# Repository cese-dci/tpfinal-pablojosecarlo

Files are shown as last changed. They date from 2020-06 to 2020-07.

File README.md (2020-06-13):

# tpfinal-pablojosecarlo

DCI CESE 10º Cohorte 2020 Pablo José Carlos Alonso Castillo

Escaner de Campos Magnéticos Superficiales (ECMag)

Descripción del dispositivo:

El objeto del scanner  es relevar los campos magnéticos a distancias de 1 a 3 mm de las superficies, correlacionando la posición de sensores magnéticos con la de un encoder absoluto y comunicar los resultados a una PC via cable USB, RS232 o por medios inalámbricos 
 
Para ese fin se implementa un circuito dividido en dos secciones con los uP ATM328 y PIC18F2550

El ATM328 se encarga de la adquisición de señales del encoder alsoluto de 12 bits, de los sensores magnéticos y de la interfaz de usuario a través de un display i2c, un buzzer y dos pulsadores.

El PIC18F2550 se encarga de las comunicaciones USB, seriales e inalámbricas y de servir de buffer de datos.

los uP cuentan con pulsadores de reseteo.

Puesto que el encoder funciona con 12V se ha dispuesto también de un convertidor DC-DC de 5V a 12V

La alimentación puede ser desde el puerto USB o con fuente externa de 5V

La salida a display i2c muestra las lecturas instantáneas de los campos magnéticos y la posición del encoder; buzzer de fuera de rango y dos pulsadores de seteo y nueva medición.

Pablo J.C. Alonso Castillo

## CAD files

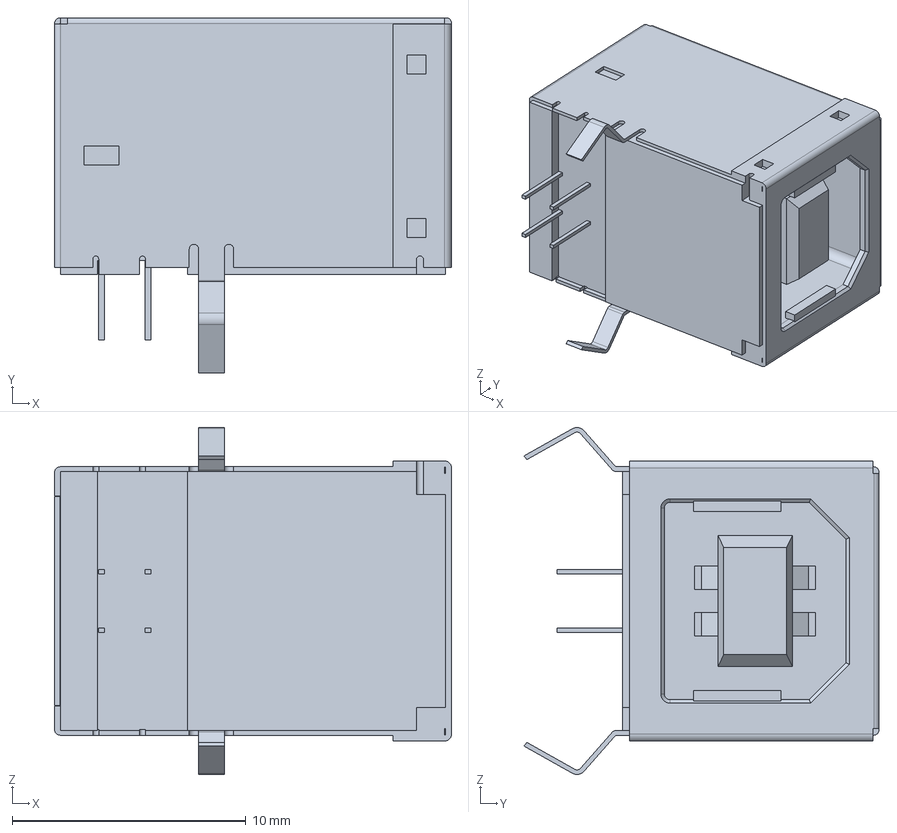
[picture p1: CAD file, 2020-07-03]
Shapes3D/USB_B_OST_USB-B1HS00_Horizontal.step
17.0 x 15.2 x 14.9 mm

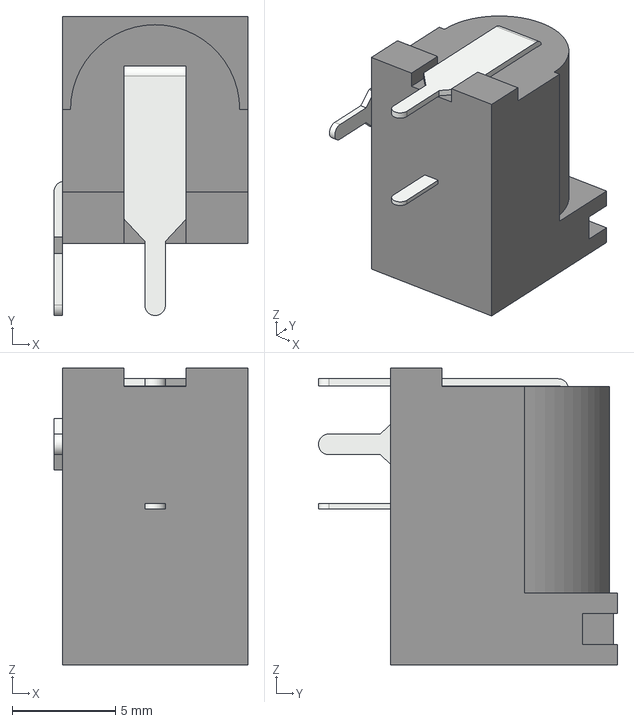
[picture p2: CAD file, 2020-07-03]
Shapes3D/CUI_PJ-102A.STEP
9.40 x 14.5 x 14.4 mm

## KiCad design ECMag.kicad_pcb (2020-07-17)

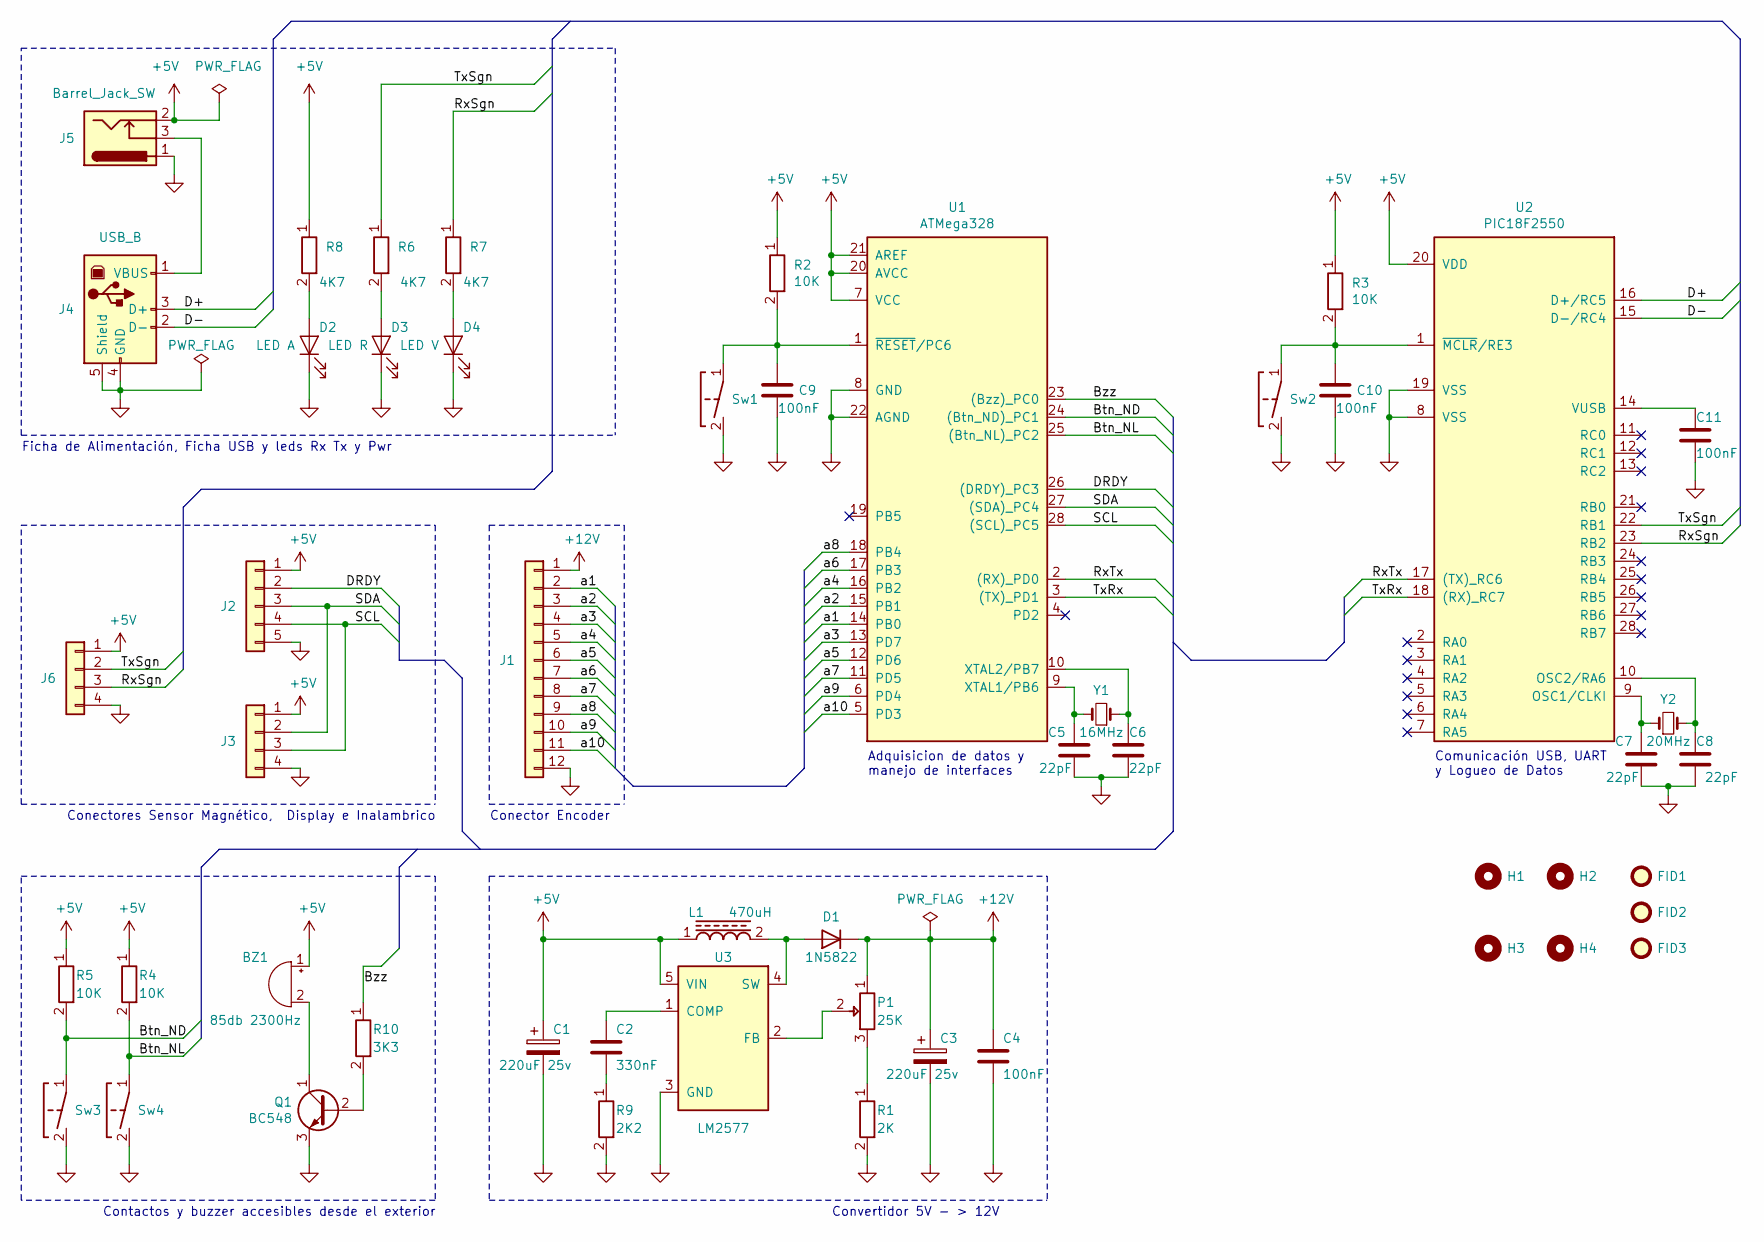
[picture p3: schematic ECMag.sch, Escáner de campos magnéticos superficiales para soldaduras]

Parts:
BZ1: 85db 2300Hz; Buzzer_12x9.5RM7.6; Digikey 102-1458-ND
C1, C3: 220uF 25v; CP_Radial_D8.0mm_P5.00mm
C2: 330nF; C_Disc_D5.1mm_W3.2mm_P5.00mm
C4, C9, C10, C11: 100nF; C_Disc_D5.1mm_W3.2mm_P5.00mm
C5, C6, C7, C8: 22pF; C_Disc_D6.0mm_W2.5mm_P5.00mm
D1: 1N5822; D_A-405_P10.16mm_Horizontal; Digikey 497-11370-1-ND
D2: LED A; LED_D3.0mm
D3: LED R; LED_D3.0mm
D4: LED V; LED_D3.0mm
FID1, FID2, FID3: Fiducial; Fiducial_1mm_Mask2mm
H1, H2, H3, H4: MountingHole; MountingHole_3.2mm_M3
J1: Conn_01x12; PinHeader_1x12_P2.54mm_Vertical; Digikey 952-3302-ND
J2: Conn_01x05; PinHeader_1x05_P2.54mm_Vertical; Digikey 952-3302-ND
J3, J6: Conn_01x04; PinHeader_1x04_P2.54mm_Vertical; Digikey 952-3302-ND
J4: USB_B; USB_B_OST_USB-B1HSxx_Horizontal; Digikey WM12785-ND
J5: Barrel_Jack_SW; BarrelJack_Wuerth_6941xx301002; Digikey CP-202A-ND
L1: 470uH; L_Radial_D7.5mm_P5.00mm_Fastron_07P; Digikey 445-174743-2-ND
P1: 25K; Potentiometer_Bourns_3266W_Vertical
Q1: BC548; TO-92_Inline; Digikey BC548-ND
R1: 2K; R_Axial_DIN0207_L6.3mm_D2.5mm_P7.62mm_Horizontal
R2, R3, R4, R5: 10K; R_Axial_DIN0207_L6.3mm_D2.5mm_P7.62mm_Horizontal
R6, R7, R8: 4K7; R_Axial_DIN0207_L6.3mm_D2.5mm_P7.62mm_Horizontal
R9: 2K2; R_Axial_DIN0207_L6.3mm_D2.5mm_P7.62mm_Horizontal
R10: 3K3; R_Axial_DIN0207_L6.3mm_D2.5mm_P7.62mm_Horizontal
Sw1, Sw2, Sw3, Sw4: Tactil Switch B3F NA; SW_PUSH_6mm_H5mm; Digikey B3F-1060
U1: ATMega328; DIP-28_W7.62mm; Digikey ATMEGA328-PU-ND
U2: PIC18F2550; DIP-28_W7.62mm; Digikey PIC18F2550-I/SP-ND
U3: LM2577; TO-220-5_P3.4x3.7mm_StaggerOdd_Lead3.8mm_Vertical; Digikey LM2577SX-ADJ/NOPBTR-ND
Y1: 16MHz; Crystal_HC49-U_Vertical; Digikey 1923-1788-ND
Y2: 20MHz; Crystal_HC49-U_Vertical; Digikey 1923-1441-ND

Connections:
+5V: BZ1.1 (-), C1.1, J2.1, J3.1, J5.2, J6.1, L1.1, R2.1, R3.1, R4.1, R5.1, R8.1, U1.7 (VCC), U1.20 (AVCC), U1.21 (AREF), U2.20 (VDD), U3.5 (VIN)
+12V: C3.1, C4.1, D1.2 (K), J1.1, P1.1
/Btn_ND: R5.2, Sw3.1, U1.24 ((Btn_ND)_PC1)
/Btn_NL: R4.2, Sw4.1, U1.25 ((Btn_NL)_PC2)
/Bzz: R10.1, U1.23 ((Bzz)_PC0)
/D+: J4.3 (D+), U2.16 (D+/RC5)
/D-: J4.2 (D-), U2.15 (D-/RC4)
/DRDY: J2.2, U1.26 ((DRDY)_PC3)
/RxSgn: J6.3, R7.1, U2.23 (RB2)
/RxTx: U1.2 ((RX)_PD0), U2.17 ((TX)_RC6)
/SCL: J2.4, J3.3, U1.28 ((SCL)_PC5)
/SDA: J2.3, J3.2, U1.27 ((SDA)_PC4)
/TxRx: U1.3 ((TX)_PD1), U2.18 ((RX)_RC7)
/TxSgn: J6.2, R6.1, U2.22 (RB1)
/a1: J1.2, U1.14 (PB0)
/a2: J1.3, U1.15 (PB1)
/a3: J1.4, U1.13 (PD7)
/a4: J1.5, U1.16 (PB2)
/a5: J1.6, U1.12 (PD6)
/a6: J1.7, U1.17 (PB3)
/a7: J1.8, U1.11 (PD5)
/a8: J1.9, U1.18 (PB4)
/a9: J1.10, U1.6 (PD4)
/a10: J1.11, U1.5 (PD3)
GND: C1.2, C3.2, C4.2, C5.2, C6.2, C7.2, C8.2, C9.2, C10.2, C11.2, D2.1 (K), D3.1 (K), D4.1 (K), J1.12, J2.5, J3.4, J4.4 (GND), J4.5 (Shield), J5.1, J6.4, Q1.3 (E), R1.2, R9.2, Sw1.2, Sw2.2, Sw3.2, Sw4.2, U1.8 (GND), U1.22 (AGND), U2.8 (VSS), U2.19 (VSS), U3.3 (GND)
unnamed: BZ1.2 (+), Q1.1 (C)
unnamed: C2.1, U3.1 (COMP)
unnamed: C2.2, R9.1
unnamed: C5.1, U1.9 (XTAL1/PB6), Y1.2
unnamed: C6.1, U1.10 (XTAL2/PB7), Y1.1
unnamed: C7.1, U2.9 (OSC1/CLKI), Y2.1
unnamed: C8.1, U2.10 (OSC2/RA6), Y2.2
unnamed: C9.1, R2.2, Sw1.1, U1.1 (~RESET~/PC6)
unnamed: C10.1, R3.2, Sw2.1, U2.1 (~MCLR~/RE3)
unnamed: C11.1, U2.14 (VUSB)
unnamed: D1.1 (A), L1.2, U3.4 (SW)
unnamed: D2.2 (A), R8.2
unnamed: D3.2 (A), R6.2
unnamed: D4.2 (A), R7.2
unnamed: J4.1 (VBUS), J5.3
unnamed: P1.2, U3.2 (FB)
unnamed: P1.3, R1.1
unnamed: Q1.2 (B), R10.2

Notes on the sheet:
Convertidor 5V - > 12V
Conector Encoder
Contactos y buzzer accesibles desde el exterior
Conectores Sensor Magnético, Display e Inalambrico
Ficha de Alimentación, Ficha USB y leds Rx Tx y Pwr
Comunicación USB, UART y Logueo de Datos
Adquisicion de datos y manejo de interfaces

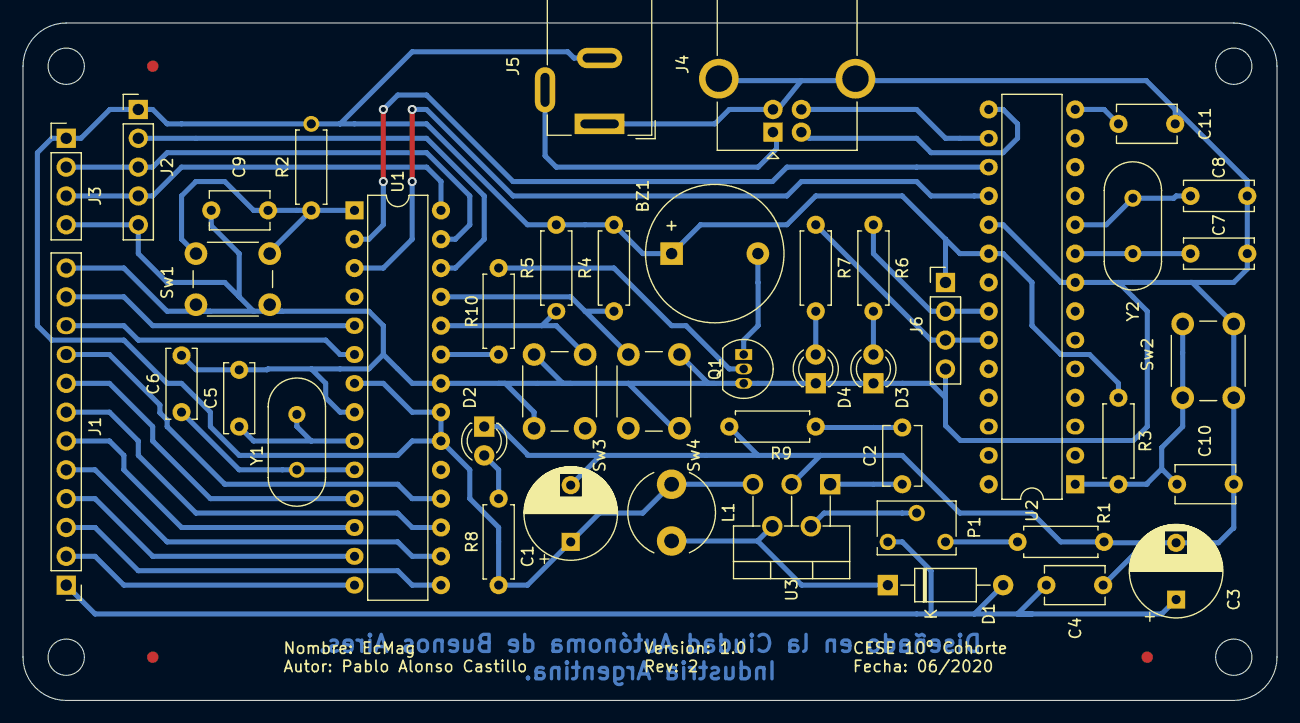
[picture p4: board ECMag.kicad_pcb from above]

Board: 2 copper layers, 110.5 x 59.7 mm, 51 parts (0 on the bottom side), 43 nets.

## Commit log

2020-05-30 Commit de lo hecho hasta el 30 de mayo de 2020
    [ECMag.kicad_pcb, ECMag.sch]
2020-06-05 Esquemáticounifilar terminado. Faltan footprints y datasheets
    [ECMag.sch]
2020-06-05 Esquemático terminado, con footprints y datasheets
    [ECMag.sch]
2020-06-05 Actualizacion de datasheets
    [ECMag.sch]
2020-06-06 Rediseño de fuente step up 5v-12v y Actualizacion de datasheets
    [ECMag.sch]
2020-06-07 compleción de huellas faltantes y reemplazo de etiquetas por buses
    [ECMag.sch]
2020-06-07 Inicio de PCB
    [ECMag.sch]
2020-06-10 agregado de valores de los componentes en el esquemático
    [ECMag.kicad_pcb, ECMag.sch]
2020-06-11 Edicion de huella de pulsadores y primer pcb
    [ECMag.kicad_pcb, ECMag.sch]
2020-06-12 Correcciones faltantes indicadas por el profesor
    [ECMag.kicad_pcb, ECMag.sch]
2020-06-13 Correcciones faltantes indicadas por el profesor - detalles
    [ECMag.sch]
2020-06-19 primera versión del pcb
    [ECMag.kicad_pcb, ECMag.sch]
2020-06-20 cambio de huellas del pulsador
    [ECMag.kicad_pcb, ECMag.sch]
2020-06-25 Arreglo de F.Silks y F.Fab
    [ECMag.kicad_pcb]
2020-06-25 Paso de los tracks de 0.25 a 0.45, tracks de senhales y potencia
    [ECMag.kicad_pcb, ECMag.sch]
2020-06-26 Planos de Tierra de Fuente Switchin de 12V y Plano General
    [ECMag.kicad_pcb]
2020-07-03 Agregadas las imagenes 3D del power jack y del USB B, corregidas esquinas del pcb, agregados fiduciarios, parametros del circuito, grilla, datos del fabricante, dimensiones del pcb, datos de serigraf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
    [CUI_PJ-102A.STEP, ECMag.kicad_pcb, ECMag.sch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]
2020-07-03 error de salvado
    [ECMag.kicad_pcb]
2020-07-03 Correcciones en los comentarios de la capa Dwgs
    [ECMag.kicad_pcb]
2020-07-03 Eliminación de Tracks superfluos tapados por otros tracks
    [ECMag.kicad_pcb]
2020-07-17 1.- Reemplaxado K por Sw en el esquemático.
    [ECMag.kicad_pcb, ECMag.sch]
2020-07-17 Arreglos finales sugeridos por el profesor. Ver archivo: notas al profesor
